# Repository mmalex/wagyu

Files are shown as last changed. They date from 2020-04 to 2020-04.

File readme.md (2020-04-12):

# 'wagyu' simple 5hp eurorack module to demonstrate STM32F405 based module design. 
## what is it?

WATCH THIS -  https://www.youtube.com/watch?v=Wm21Wc7AefM

a small eurorack module with 3 knobs, 4 DC coupled CV inputs (+-5v), an encoder, an 8x8 LED matrix display, stereo AC coupled outputs (+-8v), and stereo AC coupled audio rate inputs. the audio inputs are 'aliased' with two of the CV inputs, so that you can use one or both of them as either CV or audio inputs. for example, the 3 leftmost jacks can be used as CV inputs, then the 3 rightmost jacks are the 'audio' side, with mono in at the top and stereo out at the bottom. alternatively, the top two jacks can be used as stereo inputs.

it has an STM32F405 processor at 168Mhz, which is fast enough to do fun reverby, synthy things. it's also cheap and in-stock at JLC :)

## but what does it DO? 

it teaches me module design, and latterly, you - thru a series of (so far 2) youtube streams.

this repo is a dump of the state of the hardware design files and software as written on-stream.
the first stream was more hardware centric, but not about this specific design - https://www.youtube.com/watch?v=Xf4CxC8exFM
the second stream covered bringing up the entire sw/ folder from scratch for this design - https://www.youtube.com/watch?v=Wm21Wc7AefM

## Hardware
the files are presented in the exact state I showed on stream and submitted to JLCPCB for PCB manufacture and assembly. at the time, all SMT parts were in-stock and from their standard library. the front panel is presented as two designs that can be broken apart. I wasnt sure if 'holes' or 'no-solder-mask-circuitboard' would be better; in the end, only holes worked - so if you are submitting this, you can save yourself some money by removing the 'no-holes' half of the front panel design, by editing the kicad files and regenerating the gerbers.

the main board is a 4 layer design, mostly auto routed (sorry not sorry). It has 3 mistakes, none fatal: the euro power jack isnt perfectly centered, which causes the plastic plug to overhang by a mm or so. annoying, and could be fixed by shuffling it over a bit. it's fine if your case or the adjacent module has a bit of space there :). the I2C bus doesn't have pullups, oops; you need two 2.2k resistors pulling up to 3v3 adding. I work around this in software so it works fine without (I bit bang the I2C and go slow, using the STM's on-chip pullups). lastly, the footprint of the 8x8 LED matrix I mistakenly assumed the pins were in a square; they are not. see second video for more info, but you can just bend them and it fits. Just.

## BOM
all the SMT positioning (csv) that you can upload to JLC's assembly service is in the assembly/ subfolder; likewise, the SMT BOM with part numbers for the lcsc.com site - all chosen to be available for JLC assembly.
Once you receive the board, you need to source and add your own 'hardware':
- 3 linear taper pots, 50k -100k maybe? I got mine from thonk.co.uk, Vertical T-18 https://www.thonk.co.uk/shop/alpha-9mm-pots-vertical-t18/
- 6 thonkiconn jacks, also from thonk.co.uk
- an encoder with clicky button. eg https://www.digikey.co.uk/product-detail/en/bourns-inc/PEC11R-4215F-S0024/PEC11R-4215F-S0024-ND/4499665
- some knobs! from thonk.co.uk again.
- a 0.8" LED 8x8 matrix (single color). I got mine from adafruit, it says 'luckylight' on the side. mine was white, here's a red one: https://www.adafruit.com/product/454. in the UK, pimeroni is a great stockist of adafruit stuff.
- a eurorack 8x2 0.1" spacing male pin header for power. I stupidly soldered a right angled one onto mine- it does fit! but simpler would have just been to use bog standard 0.1" header pins, in 2 rows, and make sure to plug them into a plug before soldering to keep them at the right angle. I object to regulating 12v straight down to 3v3 and boiling the oceans - so its a 16 pin plug (for 5v). tough!
- a programming header - I use the 'STDC14 pinout' (google it), which puts a Uart along with classic SWD pins. The PCB expects a surface mount 7x2 0.05" spacing pin header. for example https://www.digikey.co.uk/product-detail/en/amphenol-icc-fci/20021121-00014T4LF/609-3730-ND/2209080. or you can just solder 4 bodge wires on over to your SWD programmer.

## SW
the software is as I left it at the end of the second stream. We've brought up all the hardware except audio input; the only files that differ from the autogenerated project are main.c and codec.h; everything else is ignorable boilerplate.
it doesn't do anything musical at this stage, but it should make a good starting point.

## stuff you might need
you need STMCube32IDE for free from ST.com to do the software side; runs on mac, windows and linux.
I used a Digilent Analog Discovery 2 as a scope & signal generator, but you don't strictly need it.
you will need some way to flash your board - an ST Link programmer for example; the new ST Link 3 Mini has exactly the right programming header, but I can't seem to find one to buy! instead, I use Nucleo boards (look on amazon for 'nucleo STM32') - they are typically under £20, give you a great prototyping platform AND a built in ST Link programmer you can use on your own standalone boards.

have fun! let me know on twitter if you get something out of this! twitter.com/mmalex

## License
I'm releasing this all into the public domain. the hardware is heavily inspired by the eurorack open source modules, and the codec & cpu parts are pretty generic.  I would appreciate if you let me know if you get any value out of this! let me know on twitter @mmalex.

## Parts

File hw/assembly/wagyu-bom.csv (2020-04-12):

Comment | Designator | Footprint | LCSC
100n | C1,C25,C11,C18,C19,C22,C23,C26,C28,C37 | Capacitor_SMD:C_0603_1608Metric | C14663
2u2 | C13,C15,C24 | Capacitor_SMD:C_0603_1608Metric | C23630
18p | C14,C12 | Capacitor_SMD:C_0603_1608Metric | C1647
10uf | C16,C17 | Capacitor_SMD:CP_Elec_5x4.5 | C249452
4.7u | C29,C27,C31,C32,C33 | Capacitor_SMD:C_0603_1608Metric | C19666
220pf | C30,C34 | Capacitor_SMD:C_0603_1608Metric | C1603
220p | C5,C6,C7,C8,C20,C21 | Capacitor_SMD:C_0603_1608Metric | C1603
10u | C9,C4,C3,C2,C10,C35,C36 | Capacitor_SMD:C_0805_2012Metric | C15850
100k | R1,R3,R2,R6,R7,R8,R36 | Resistor_SMD:R_0603_1608Metric | C25803
10k | R13 | Resistor_SMD:R_0603_1608Metric | C25804
5.6k | R16,R17,R24,R22,R25,R23 | Resistor_SMD:R_0603_1608Metric | C23189
1k | R20,R21 | Resistor_SMD:R_0603_1608Metric | C21190
100 | R26,R27,R28,R29,R30,R31,R32,R33,R34 | Resistor_SMD:R_0603_1608Metric | C22775
3k3 | R35 | Resistor_SMD:R_0603_1608Metric | C22978
120k | R4,R5,R37 | Resistor_SMD:R_0603_1608Metric | C25808
33k | R9,R10,R11,R12,R18,R14,R19,R15 | Resistor_SMD:R_0603_1608Metric | C4216
MCP6004 | U1 | Package_SO:TSSOP-14_4.4x5mm_P0.65mm | C50282
LM1117-3.3 | U2,U3 | Package_TO_SOT_SMD:SOT-223-3_TabPin2 | C6186
STM32F405RGTx | U4 | Package_QFP:LQFP-64_10x10mm_P0.5mm | C15742
TL072 | U5 | Package_SO:SOIC-8_3.9x4.9mm_P1.27mm | C6961
WM8758B | U6 | Package_DFN_QFN:QFN-32-1EP_5x5mm_P0.5mm_EP3.45x3.45mm | C323840
LM4040DBZ-5 | U7 | Package_TO_SOT_SMD:SOT-23 | C156291
Crystal_GND24 | Y1 | Crystal:Crystal_SMD_Abracon_ABM8G-4Pin_3.2x2.5mm | C13738

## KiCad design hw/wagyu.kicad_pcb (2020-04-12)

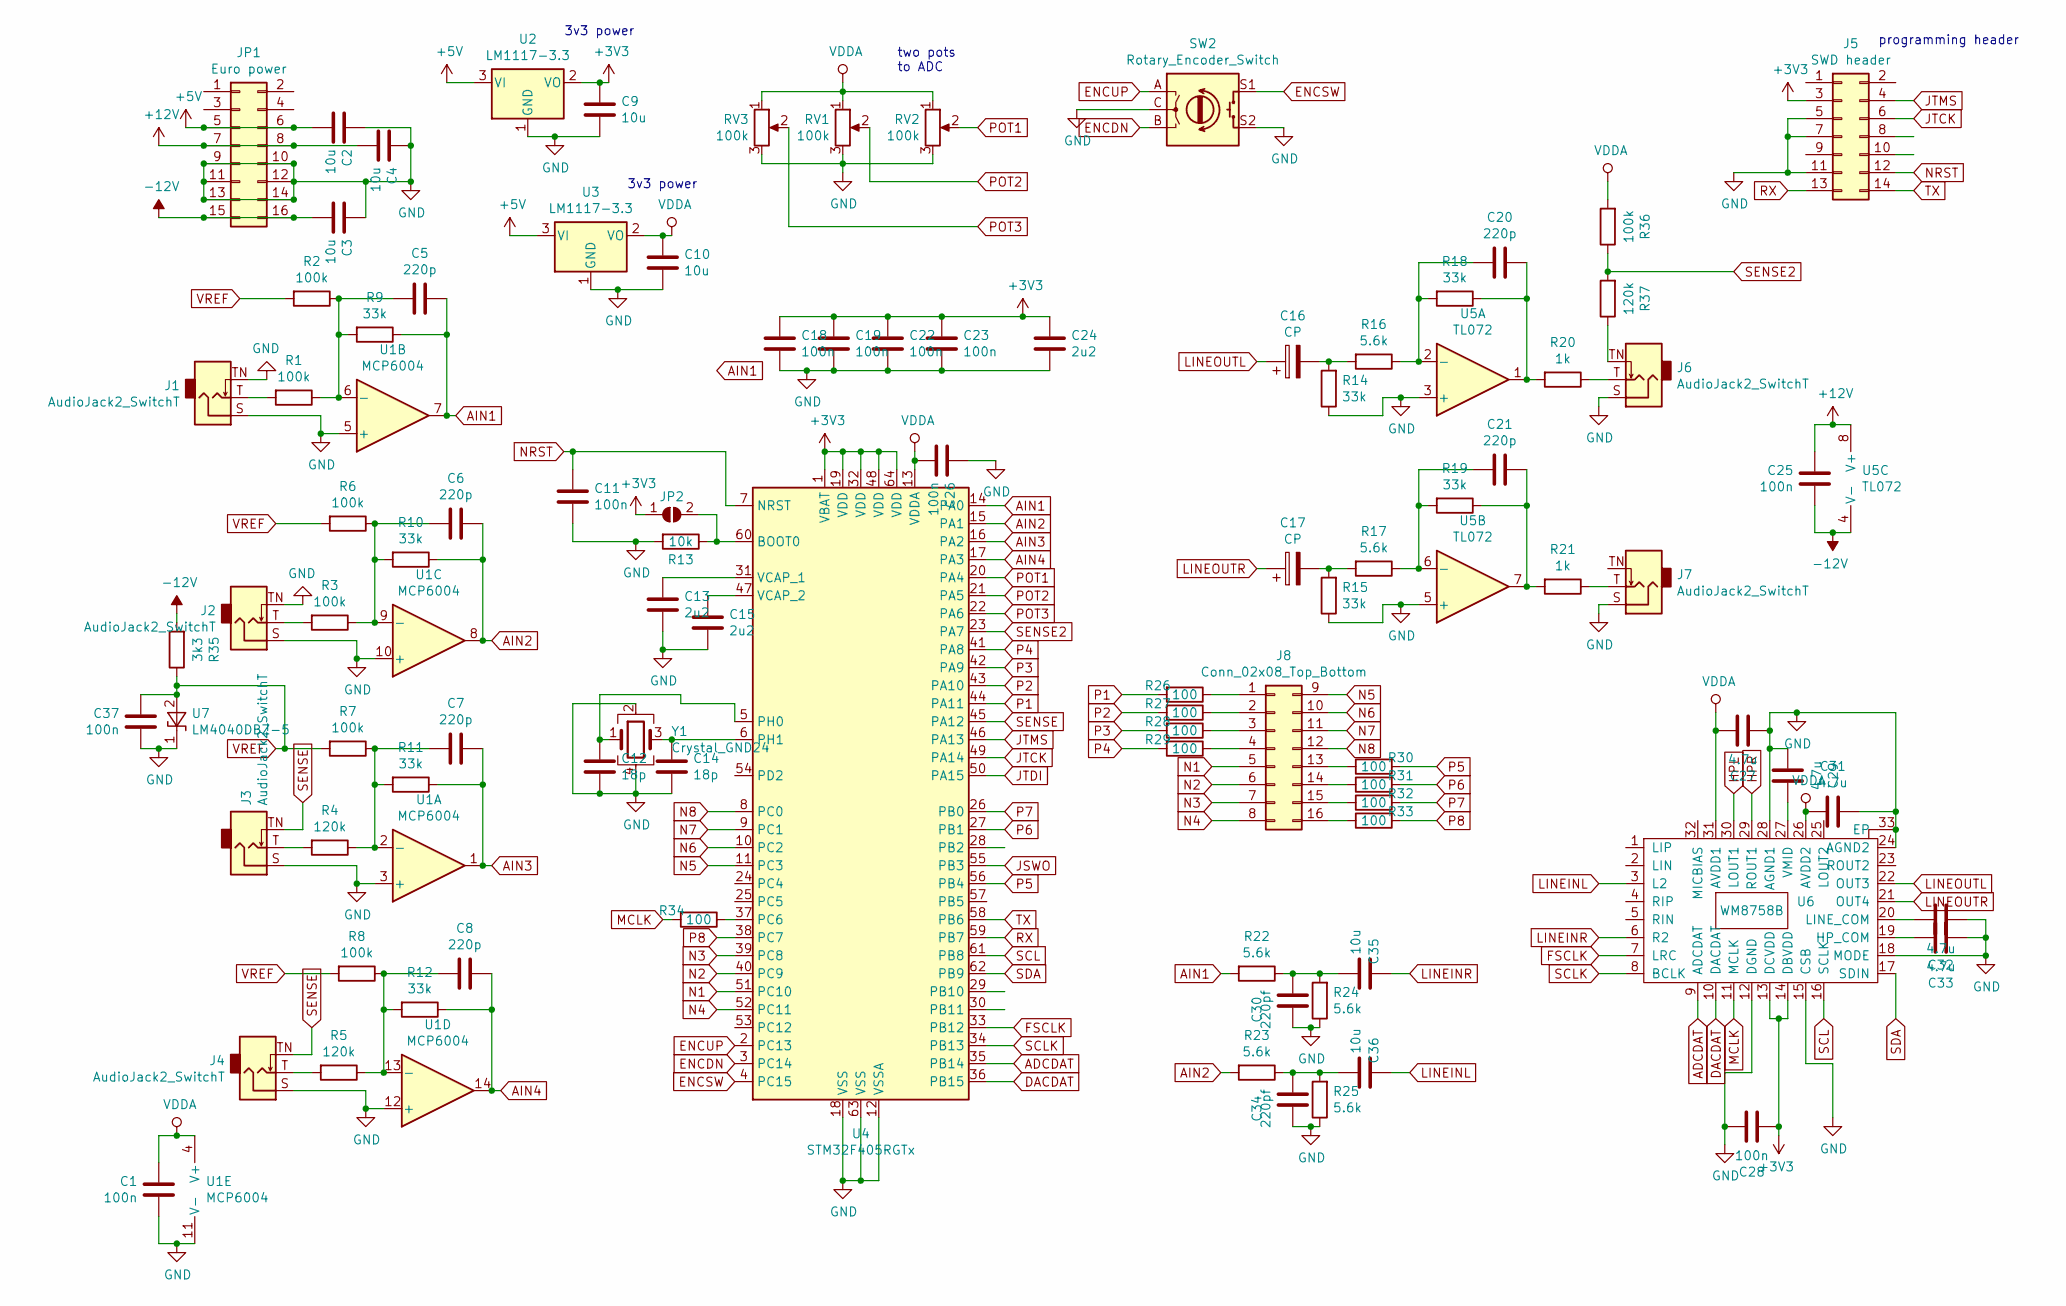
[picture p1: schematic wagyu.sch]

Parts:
C1, C11, C18, C19, C22, C23, C25, C26, C37: 100n; C_0603_1608Metric
C2, C3, C4, C9, C10, C35, C36: 10u; C_0805_2012Metric
C5, C6, C7, C8, C20, C21: 220p; C_0603_1608Metric
C12, C14: 18p; C_0603_1608Metric
C13, C15, C24: 2u2; C_0603_1608Metric
C16, C17: CP; CP_Elec_5x4.5
C27, C29, C31, C32, C33: 4.7u; C_0603_1608Metric
C28: 100n; C_0603_1608Metric; LCSC C19666
C30, C34: 220pf; C_0603_1608Metric
J1, J2, J3, J4, J6, J7: AudioJack2_SwitchT; Jack_3.5mm_QingPu_WQP-PJ398SM_Vertical_CircularHoles
J5: SWD header; PinHeader_2x07_P1.27mm_Vertical_SMD
J8: Conn_02x08_Top_Bottom; led8x8
JP1: Euro power; PinHeader_2x08_P2.54mm_Vertical
JP2: SolderJumper_2_Open; SolderJumper-2_P1.3mm_Open_Pad1.0x1.5mm
R1, R2, R3, R6, R7, R8, R36: 100k; R_0603_1608Metric
R4, R5, R37: 120k; R_0603_1608Metric
R9, R10, R11, R12, R14, R15, R18, R19: 33k; R_0603_1608Metric
R13: 10k; R_0603_1608Metric
R16, R17, R22, R23, R24, R25: 5.6k; R_0603_1608Metric
R20, R21: 1k; R_0603_1608Metric
R26, R27, R28, R29, R30, R31, R32, R33, R34: 100; R_0603_1608Metric
R35: 3k3; R_0603_1608Metric
RV1, RV2, RV3: 100k; Potentiometer_Alpha_RD901F-40-00D_Single_Vertical
SW2: Rotary_Encoder_Switch; RotaryEncoder_Alps_EC11E-Switch_Vertical_H20mm
U1: MCP6004; TSSOP-14_4.4x5mm_P0.65mm
U2, U3: LM1117-3.3; SOT-223-3_TabPin2
U4: STM32F405RGTx; LQFP-64_10x10mm_P0.5mm
U5: TL072; SOIC-8_3.9x4.9mm_P1.27mm
U6: WM8758B; QFN-32-1EP_5x5mm_P0.5mm_EP3.45x3.45mm; LCSC C323840
U7: LM4040DBZ-5; SOT-23
Y1: Crystal_GND24; Crystal_SMD_Abracon_ABM8G-4Pin_3.2x2.5mm

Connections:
+3V3: C9.1, C18.1, C19.1, C22.1, C23.1, C24.1, C28.2, J5.3, JP2.1 (A), U2.2 (VO), U4.1 (VBAT), U4.19 (VDD), U4.32 (VDD), U4.48 (VDD), U4.64 (VDD), U6.13 (DCVDD), U6.14 (DBVDD)
+5V: C2.2, JP1.5, JP1.6, U2.3 (VI), U3.3 (VI)
+12V: C4.2, C25.2, JP1.7, JP1.8, U5.8 (V+)
-12V: C3.2, C25.1, JP1.15, JP1.16, R35.2, U5.4 (V-)
ADCDAT: U4.35 (PB14), U6.9 (ADCDAT)
AIN1: C5.1, R9.1, R22.2, U1.7, U4.14 (PA0)
AIN2: C6.1, R10.1, R23.2, U1.8, U4.15 (PA1)
AIN3: C7.1, R11.1, U1.1, U4.16 (PA2)
AIN4: C8.1, R12.1, U1.14, U4.17 (PA3)
DACDAT: U4.36 (PB15), U6.10 (DACDAT)
ENCDN: SW2.B, U4.3 (PC14)
ENCSW: SW2.S1, U4.4 (PC15)
ENCUP: SW2.A, U4.2 (PC13)
FSCLK: U4.33 (PB12), U6.7 (LRC)
GND: C1.1, C2.1, C3.1, C4.1, C9.2, C10.2, C11.2, C12.2, C13.2, C14.2, C15.2, C18.2, C19.2, C22.2, C23.2, C24.2, C26.1, C27.2, C28.1, C29.2, C30.1, C31.1, C32.2, C33.2, C34.1, C37.1, J1.S, J1.TN, J2.S, J2.TN, J3.S, J4.S, J5.5, J5.7, J5.11, J6.S, J7.S, JP1.9, JP1.10, JP1.11, JP1.12, JP1.13, JP1.14, R13.2, R14.1, R15.1, R24.1, R25.1, RV1.3, RV2.3, RV3.3, SW2.C, SW2.S2, U1.3 (+), U1.5 (+), U1.10 (+), U1.11 (V-), U1.12 (+), U2.1 (GND), U3.1 (GND), U4.12 (VSSA), U4.18 (VSS), U4.63 (VSS), U5.3 (+), U5.5 (+), U6.12 (DGND), U6.15 (CSB), U6.18 (MODE), U6.24 (AGND2), U6.28 (AGND1), U6.33 (EP), U7.1 (K), Y1.2, Y1.4
HPL: U6.30 (LOUT1)
HPR: U6.29 (ROUT1)
JSWO: U4.55 (PB3)
JTCK: J5.6, U4.49 (PA14)
JTDI: U4.50 (PA15)
JTMS: J5.4, U4.46 (PA13)
LINEINL: C36.1, U6.3 (L2)
LINEINR: C35.1, U6.6 (R2)
LINEOUTL: C16.1, U6.22 (OUT3)
LINEOUTR: C17.1, U6.21 (OUT4)
MCLK: R34.2, U6.11 (MCLK)
N1: J8.5, U4.51 (PC10)
N2: J8.6, U4.40 (PC9)
N3: J8.7, U4.39 (PC8)
N4: J8.8, U4.52 (PC11)
N5: J8.9, U4.11 (PC3)
N6: J8.10, U4.10 (PC2)
N7: J8.11, U4.9 (PC1)
N8: J8.12, U4.8 (PC0)
NRST: C11.1, J5.12, U4.7 (NRST)
unnamed: C5.2, R1.1, R2.1, R9.2, U1.6 (-)
unnamed: C6.2, R3.1, R6.1, R10.2, U1.9 (-)
unnamed: C7.2, R4.1, R7.1, R11.2, U1.2 (-)
unnamed: C8.2, R5.1, R8.1, R12.2, U1.13 (-)
unnamed: C12.1, U4.5 (PH0), Y1.1
unnamed: C13.1, U4.31 (VCAP_1)
unnamed: C14.1, U4.6 (PH1), Y1.3
unnamed: C15.1, U4.47 (VCAP_2)
unnamed: C16.2, R14.2, R16.2
unnamed: C17.2, R15.2, R17.2
unnamed: C20.1, R18.1, R20.2, U5.1
unnamed: C20.2, R16.1, R18.2, U5.2 (-)
unnamed: C21.1, R19.1, R21.2, U5.7
unnamed: C21.2, R17.1, R19.2, U5.6 (-)
unnamed: C29.1, U6.27 (VMID)
unnamed: C30.2, C35.2, R22.1, R24.2
unnamed: C32.1, U6.20 (LINE_COM)
unnamed: C33.1, U6.19 (HP_COM)
unnamed: C34.2, C36.2, R23.1, R25.2
unnamed: J1.T, R1.2
unnamed: J2.T, R3.2
unnamed: J3.T, R4.2
unnamed: J4.T, R5.2
unnamed: J6.T, R20.1
unnamed: J6.TN, R37.1
unnamed: J7.T, R21.1
unnamed: J8.1, R26.1
unnamed: J8.2, R27.1
unnamed: J8.3, R28.1
unnamed: J8.4, R29.1
unnamed: J8.13, R30.1
unnamed: J8.14, R31.1
unnamed: J8.15, R32.1
unnamed: J8.16, R33.1
unnamed: JP2.2 (B), R13.1, U4.60 (BOOT0)
unnamed: R34.1, U4.37 (PC6)
P1: R26.2, U4.44 (PA11)
P2: R27.2, U4.43 (PA10)
P3: R28.2, U4.42 (PA9)
P4: R29.2, U4.41 (PA8)
P5: R30.2, U4.56 (PB4)
P6: R31.2, U4.27 (PB1)
P7: R32.2, U4.26 (PB0)
P8: R33.2, U4.38 (PC7)
POT1: RV2.2, U4.20 (PA4)
POT2: RV1.2, U4.21 (PA5)
POT3: RV3.2, U4.22 (PA6)
RX: J5.13, U4.59 (PB7)
SCL: U4.61 (PB8), U6.16 (SCLK)
SCLK: U4.34 (PB13), U6.8 (BCLK)
SDA: U4.62 (PB9), U6.17 (SDIN)
SENSE: J3.TN, J4.TN, U4.45 (PA12)
SENSE2: R36.1, R37.2, U4.23 (PA7)
TX: J5.14, U4.58 (PB6)
VDDA: C1.2, C10.1, C26.2, C27.1, C31.2, R36.2, RV1.1, RV2.1, RV3.1, U1.4 (V+), U3.2 (VO), U4.13 (VDDA), U6.26 (AVDD2), U6.31 (AVDD1)
VREF: C37.2, R2.2, R6.2, R7.2, R8.2, R35.1, U7.2 (A)

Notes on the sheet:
two pots to ADC
3v3 power
programming header

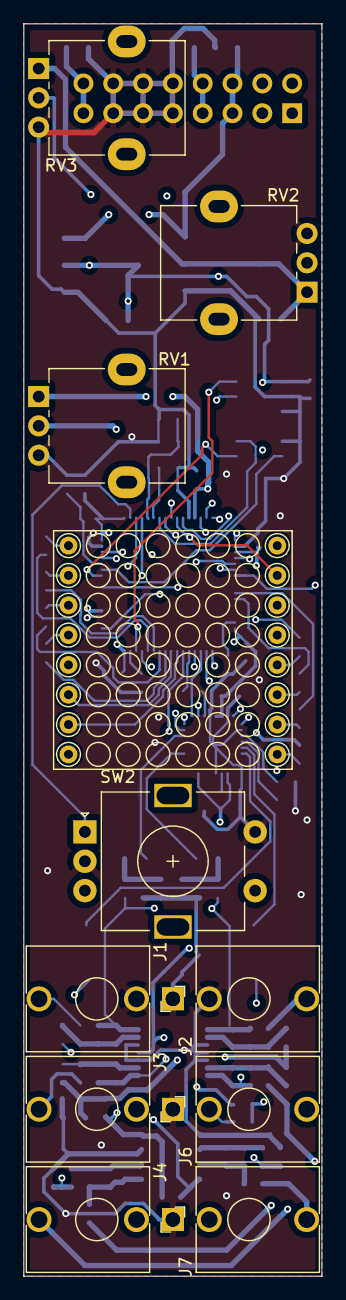
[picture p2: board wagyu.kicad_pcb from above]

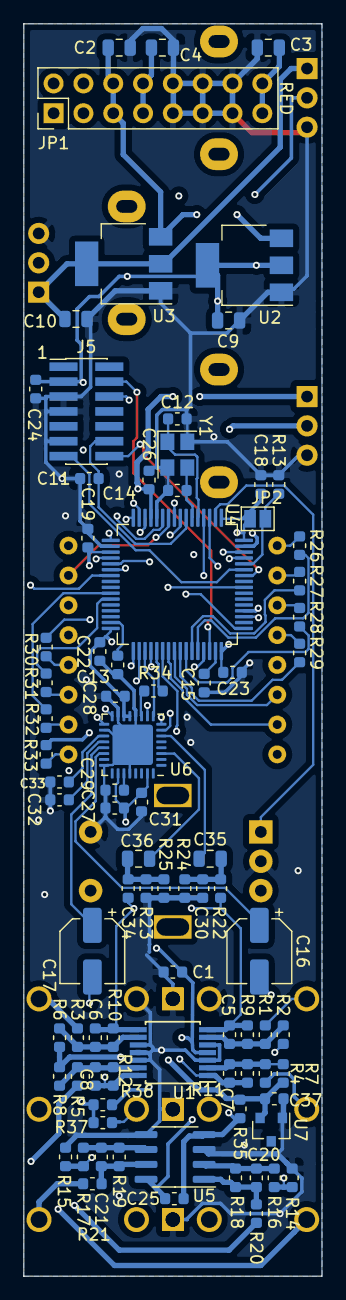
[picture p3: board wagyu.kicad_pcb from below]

Board: 4 copper layers, 25.4 x 106.7 mm, 96 parts (85 on the bottom side), 87 nets.

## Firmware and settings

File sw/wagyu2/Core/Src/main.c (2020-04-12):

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

/* Includes ------------------------------------------------------------------*/
#include "main.h"

/* USER CODE BEGIN Includes */
#include <math.h>
#include <stdarg.h>
#include <stdio.h>
#include <string.h>

/* USER CODE END Includes */

ADC_HandleTypeDef hadc1;
DMA_HandleTypeDef hdma_adc1;

I2S_HandleTypeDef hi2s2;
DMA_HandleTypeDef hdma_spi2_tx;
DMA_HandleTypeDef hdma_i2s2_ext_rx;

TIM_HandleTypeDef htim1;
TIM_HandleTypeDef htim2;
TIM_HandleTypeDef htim3;

UART_HandleTypeDef huart1;

void SystemClock_Config(void);
static void MX_GPIO_Init(void);
static void MX_DMA_Init(void);
static void MX_USART1_UART_Init(void);
static void MX_TIM1_Init(void);
static void MX_TIM3_Init(void);
static void MX_ADC1_Init(void);
static void MX_TIM2_Init(void);
static void MX_I2S2_Init(void);
/* USER CODE BEGIN 0 */

void DebugLog(const char *fmt, ...) {
	char buf[256];
	va_list args;
	va_start(args, fmt);
	int n = vsnprintf(buf, sizeof(buf), fmt, args);
	va_end(args);
	HAL_UART_Transmit(&huart1, (unsigned char*) buf, n, 10000);
}

uint8_t vram[8][8];
#define N 64
static short txbuf[N*4];
static short rxbuf[N*4];

const static uint8_t ypins[8]={TIM_CHANNEL_4,TIM_CHANNEL_3,TIM_CHANNEL_2,TIM_CHANNEL_1,TIM_CHANNEL_1,TIM_CHANNEL_4,TIM_CHANNEL_3,TIM_CHANNEL_2};
const static uint8_t xpins[8]={10,9,8,11,3,2,1,0};

void UpdateLEDs(void)
{
	  static int x=0;
	  HAL_GPIO_WritePin(GPIOC, 1<<xpins[x], GPIO_PIN_RESET);
	  x=(x+1)&7;
	  for (int y=0;y<8;++y)
		  __HAL_TIM_SET_COMPARE((y>=4)?&htim3:&htim1, ypins[y], vram[y][x]);
	  HAL_GPIO_WritePin(GPIOC, 1<<xpins[x], GPIO_PIN_SET);
}


static uint16_t adcbuf[7*8];

void HAL_I2S_TxCpltCallback (I2S_HandleTypeDef * hi2s) {
	int i=1;
}
void HAL_I2S_TxHalfCpltCallback (I2S_HandleTypeDef * hi2s) {
	int i=1;
}

//void HAL_ADC_ConvCpltCallback(ADC_HandleTypeDef *hadc) {
//	int i=1;
//}

volatile int enc_val = 0;
int prevc;
void UpdateEncoder(void) {
	int c=(GPIOC->IDR >> 13) & 3;
	int change = c^prevc;
	if (!change)
		return;
	enc_val+=(((c<<1)^(prevc))&2)-1;
	prevc=c;
}

void HAL_GPIO_EXTI_Callback(uint16_t GPIO_Pin) {
	UpdateEncoder();
}

#include "codec.h"

/* USER CODE END 0 */

/**
  * @brief  The application entry point.
  * @retval int
  */
int main(void)
{
  /* MCU Configuration--------------------------------------------------------*/

  /* Reset of all peripherals, Initializes the Flash interface and the Systick. */
  HAL_Init();

  /* Configure the system clock */
  SystemClock_Config();

  /* Initialize all configured peripherals */
  MX_GPIO_Init();
  MX_DMA_Init();
  MX_USART1_UART_Init();
  MX_TIM1_Init();
  MX_TIM3_Init();
  MX_ADC1_Init();
  MX_TIM2_Init();
  MX_I2S2_Init();
  /* USER CODE BEGIN 2 */
  DebugLog("hello world\r\n");
  HAL_TIM_PWM_Start(&htim1, TIM_CHANNEL_1);
  HAL_TIM_PWM_Start(&htim1, TIM_CHANNEL_2);
  HAL_TIM_PWM_Start(&htim1, TIM_CHANNEL_3);
  HAL_TIM_PWM_Start(&htim1, TIM_CHANNEL_4);
  HAL_TIM_PWM_Start(&htim3, TIM_CHANNEL_1);
  HAL_TIM_PWM_Start(&htim3, TIM_CHANNEL_2);
  HAL_TIM_PWM_Start(&htim3, TIM_CHANNEL_3);
  HAL_TIM_PWM_Start(&htim3, TIM_CHANNEL_4);
  HAL_ADC_Start_DMA(&hadc1,(uint32_t*)&adcbuf, 7*8);
  HAL_TIM_Base_Start(&htim2);

  UpdateEncoder();
  enc_val=0;

  for (int i=0;i<N*4;++i)
	  txbuf[i]=32767.f * sinf(i*3.141592f/2.f/N);
  int rv;
  rv = HAL_I2S_Transmit_DMA(&hi2s2, (uint16_t*) txbuf, sizeof(txbuf) / 2);
  /*
 rv= HAL_I2SEx_TransmitReceive_DMA(&hi2s2, (uint16_t*) txbuf, (uint16_t*)rxbuf, sizeof(rxbuf) / 2);
 // fix st's shit
 hi2s2.hdmatx->XferCpltCallback = allcplt;
 hi2s2.hdmatx->XferHalfCpltCallback = halfcplt;
 hi2s2.hdmarx->XferCpltCallback = 0;
 hi2s2.hdmarx->XferHalfCpltCallback = 0;
*/

  codec_init();



  /* USER CODE END 2 */

  /* Infinite loop */
  /* USER CODE BEGIN WHILE */
  while (1)
  {
    /* USER CODE END WHILE */

    /* USER CODE BEGIN 3 */
//	  DebugLog("%d %d %d\r", adcbuf[4], adcbuf[5], adcbuf[6]);
	  int x0=(adcbuf[6]^4095)+adcbuf[2]-2048;
	  int y0=(adcbuf[4]^4095)+adcbuf[3]-2048;
	  int r0=((adcbuf[5]^4095)+256);
	  r0*=r0;
	  for (int y=0;y<8;++y) {
		  int y1=(y*512)+256;
		  int dy=(y1-y0);
		  dy*=dy;
		  for (int x=0;x<8;++x) {
			  int x1=(x*512)+256;
			  int dx=(x1-x0);
			  dx*=dx;
			  // linear pixel brightness, 0=black , 255=bright
			  int k=(int)(255.f*exp2f((dx+dy)*(-4.f/r0)));
			  if (x+y*8 == enc_val/4)
				  k=255;
			  if (!((GPIOC->IDR >> 15)&1))
				  k=255-k;
			  // flip it coz I got the +/- pins backwards and square for gamma
			  vram[y][x]=255-((k*k)>>8);
		  }
	  }
	  DebugLog("%d    \r\n",enc_val);
  }
  /* USER CODE END 3 */
}

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


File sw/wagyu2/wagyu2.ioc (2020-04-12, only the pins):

Mcu.UserName=STM32F405RGTx
PA0-WKUP.Signal=ADCx_IN0
PA1.Signal=ADCx_IN1
PA10.Signal=S_TIM1_CH3
PA11.Signal=S_TIM1_CH4
PA13.Signal=SYS_JTMS-SWDIO
PA14.Signal=SYS_JTCK-SWCLK
PA2.Signal=ADCx_IN2
PA3.Signal=ADCx_IN3
PA4.Signal=ADCx_IN4
PA5.Signal=ADCx_IN5
PA6.Signal=ADCx_IN6
PA8.Signal=S_TIM1_CH1
PA9.Signal=S_TIM1_CH2
PB0.Signal=S_TIM3_CH3
PB1.Signal=S_TIM3_CH4
PB12.Signal=I2S2_WS
PB13.Signal=I2S2_CK
PB14.Signal=I2S2_ext_SD
PB15.Signal=I2S2_SD
PB4.Signal=S_TIM3_CH1
PB6.Signal=USART1_TX
PB7.Signal=USART1_RX
PB8.Signal=GPIO_Output
PB9.Signal=GPIO_Output
PC0.Signal=GPIO_Output
PC1.Signal=GPIO_Output
PC10.Signal=GPIO_Output
PC11.Signal=GPIO_Output
PC13-ANTI_TAMP.Signal=GPXTI13
PC14-OSC32_IN.Signal=GPXTI14
PC15-OSC32_OUT.Signal=GPIO_Input
PC2.Signal=GPIO_Output
PC3.Signal=GPIO_Output
PC6.Signal=I2S2_MCK
PC7.Signal=S_TIM3_CH2
PC8.Signal=GPIO_Output
PC9.Signal=GPIO_Output
PH0-OSC_IN.Signal=RCC_OSC_IN
PH1-OSC_OUT.Signal=RCC_OSC_OUT

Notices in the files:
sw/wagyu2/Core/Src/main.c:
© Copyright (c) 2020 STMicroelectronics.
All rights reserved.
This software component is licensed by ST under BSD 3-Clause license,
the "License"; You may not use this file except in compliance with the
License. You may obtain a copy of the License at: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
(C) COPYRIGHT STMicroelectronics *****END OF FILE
